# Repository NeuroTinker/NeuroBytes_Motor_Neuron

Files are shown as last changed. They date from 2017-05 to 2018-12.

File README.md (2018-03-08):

# NeuroBytes Motor Neuron
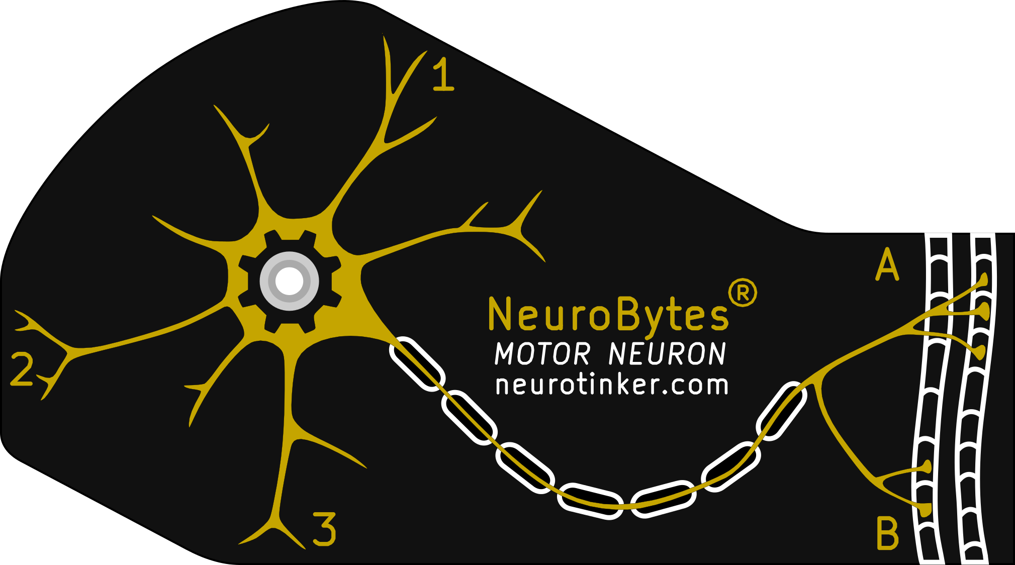
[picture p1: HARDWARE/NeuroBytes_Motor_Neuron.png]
NeuroBytes Motor Neuron PCB front

The NeuroBytes Motor Neuron is an open-source hardware neuron simulator designed and sold by [NeuroTinker, LLC](http://www.neurotinker.com/). 

All NeuroBytes products are based on the ST32L0x series of ARM Cortex-M0+ 32-bit microcontrollers. The boards were designed in KiCad and Inkscape and are released under the terms of the Creative Commons Attribution-ShareAlike 4.0 license, available here: http://creativecommons.org/licenses/by-sa/4.0/. The NeuroBytes Motor Neuron is Certified Open Source Hardware as defined by [OSHWA](https://www.oshwa.org), certification number US000109.


OSHWA Certification

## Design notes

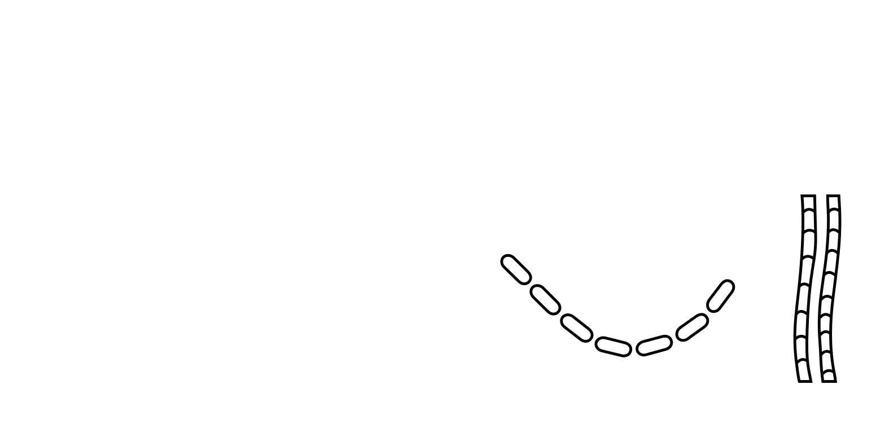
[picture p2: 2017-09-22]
HARDWARE/silk.png

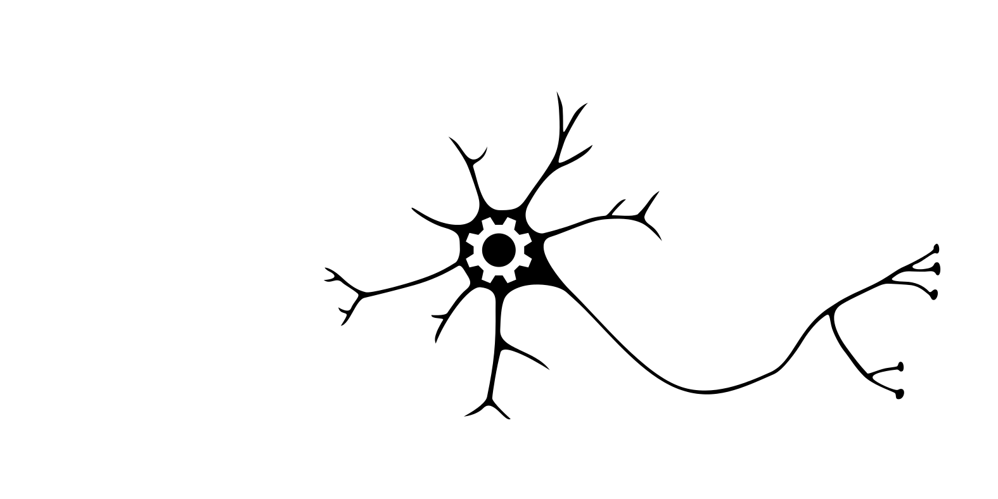
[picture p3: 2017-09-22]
HARDWARE/mask.png

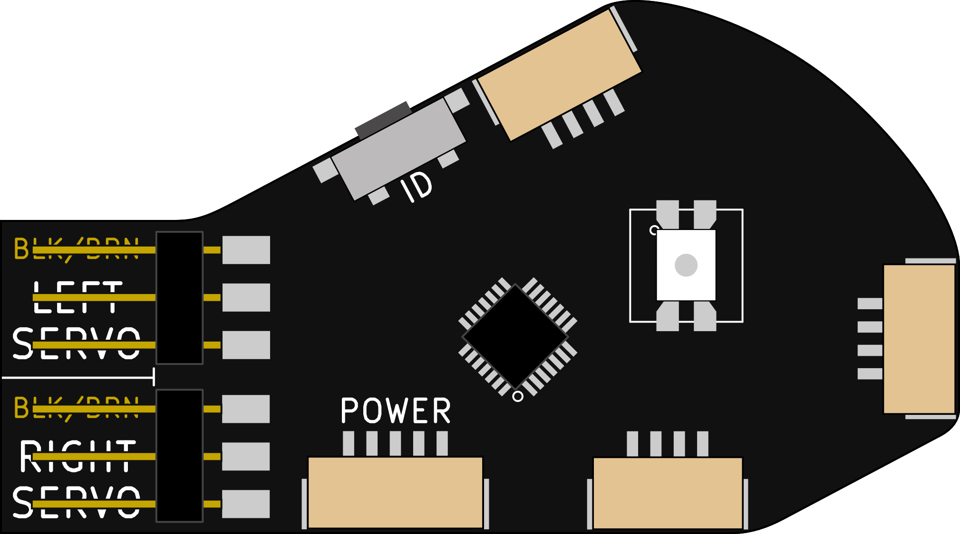
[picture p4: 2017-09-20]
HARDWARE/NeuroBytes_Motor_Neuron_back.png

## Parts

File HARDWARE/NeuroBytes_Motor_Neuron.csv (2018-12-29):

Ref | Qty | Value | Link | Mfr | Mfr Part # | Package | RoHS | Subs Allowed
C3 C5 | 2 | 0u1 | https://www.digikey.com/product-detail/en/taiyo-yuden/LMK105BJ104KV-F/587-1227-2-ND/930579 | Taiyo Yuden | LMK105BJ104KV-F | C0402 | Yes | Yes
C1 C4 | 2 | 1u | https://www.digikey.com/product-detail/en/taiyo-yuden/LMK107B7105KA-T/587-1242-2-ND/930594 | Taiyo Yuden | LMK107B7105KA-T | C0603 | Yes | Yes
C2 | 1 | 10u | https://www.digikey.com/product-detail/en/taiyo-yuden/EMK316B7106KL-TD/587-2395-2-ND/2178914 | Taiyo Yuden | EMK316B7106KL-TD | C1206 | Yes | Yes
C6 C7 | 2 | 22u | https://www.digikey.com/product-detail/en/taiyo-yuden/EMK316BB7226ML-T/587-4319-2-ND/5361244 | Taiyo Yuden | EMK316BB7226M | C1206 | Yes | Yes
D1 | 1 | LED_RABG | https://www.digikey.com/product-detail/en/sunled/XZMDKCBDDG45S-9/1497-1257-2-ND/4902045 | SunLED | XZMDKCBDDG45S-9 | SMT | Yes | No
P1 P2 P3 | 3 | JST_GH_4POS | https://www.digikey.com/product-detail/en/jst-sales-america-inc/SM04B-GHS-TB-LF-SN/455-1566-2-ND/807788 | JST | SM04B-GHS-TB(LF)(SN)- | SMT | Yes | No
P4 P5 | 2 | SERVO_CONN | https://www.digikey.com/product-detail/en/harwin-inc/M20-8890345/952-3232-ND/6565716 | Harwin | M20-8900305 | HDR_3POS_SMT | Yes | No
P6 | 1 | JST_GH_5-pos | https://www.digikey.com/product-detail/en/jst-sales-america-inc/SM05B-GHS-TB-LF-SN/455-1567-2-ND/807789 | JST | SM05B-GHS-TB(LF)(SN) | SMT | Yes | No
Q1 Q2 Q3 | 3 | MMBT3904 | https://www.digikey.com/product-detail/en/micro-commercial-co/MMBT3904-TP/MMBT3904TPMSTR-ND/717280 | Micro Commercial Co | MMBT3904-TP | SOT23-3L | Yes | Yes
R1 | 1 | 150 | https://www.digikey.com/product-detail/en/yageo/RC0402FR-07150RL/311-150LRCT-ND/729490 | Yageo | RC0402FR-07150RL | R0402 | Yes | Yes
R2 R3 | 2 | 100 | https://www.digikey.com/product-detail/en/yageo/RC0402FR-07100RL/311-100LRTR-ND/726527 | Yageo | RC0402FR-07100RL | R0402 | Yes | Yes
R4 | 1 | JMP | https://www.digikey.com/product-detail/en/yageo/RC0402JR-070RL/311-0.0JRTR-ND/726406 | Yageo | RC0402JR-070RL | R0402 | Yes | Yes
R5 R6 R7 | 3 | 1k | https://www.digikey.com/product-detail/en/yageo/RC0402FR-071KL/311-1.00KLRTR-ND/726513 | Yageo | RC0402FR-071KL | R0402 | Yes | Yes
SW1 | 1 | SW_PUSH | https://www.digikey.com/product-detail/en/e-switch/TL3330AF130QG/EG4388TR-ND/1426835 | E-Switch | TL3330AF130QG | SMT | Yes | No
U1 | 1 | STM32L011Gx | http://www.mouser.com/ProductDetail/STMicroelectronics/STM32L011G4U6/ | ST Microelectronics | STM32L011G4U6 | UFQFPN28 | Yes | No
U2 | 1 | LD3985G33R | https://www.digikey.com/product-detail/en/on-semiconductor/NCP114BSN330T1G/NCP114BSN330T1GOSTR-ND/6560606 | ON Semiconductor | NCP114BSN330T1G | SOT23-5L | Yes | Yes
U3 | 1 | RClamp0503F | https://www.digikey.com/product-detail/en/semtech-corporation/RCLAMP0503F.TCT/RCLAMP0503F.TCTTR-ND/5113629 | Semtech Corporation | RCLAMP0503F.TCT | 5-TSSOP | Yes | No
BOM made with KICAD_BOM_WIZARD (https://github.com/HashDefineElectronics/KiCad_BOM_Wizard.git)
Generated Wed 23 May 2018 03:11:21 PM CDT

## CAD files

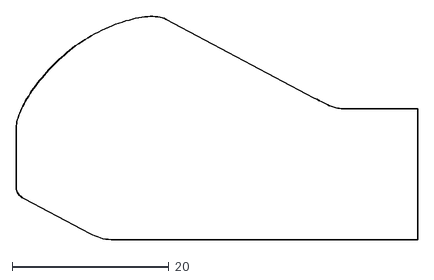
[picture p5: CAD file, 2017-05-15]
HARDWARE/NeuroBytes_Motor_Neuron.dxf
51.2 x 28.4

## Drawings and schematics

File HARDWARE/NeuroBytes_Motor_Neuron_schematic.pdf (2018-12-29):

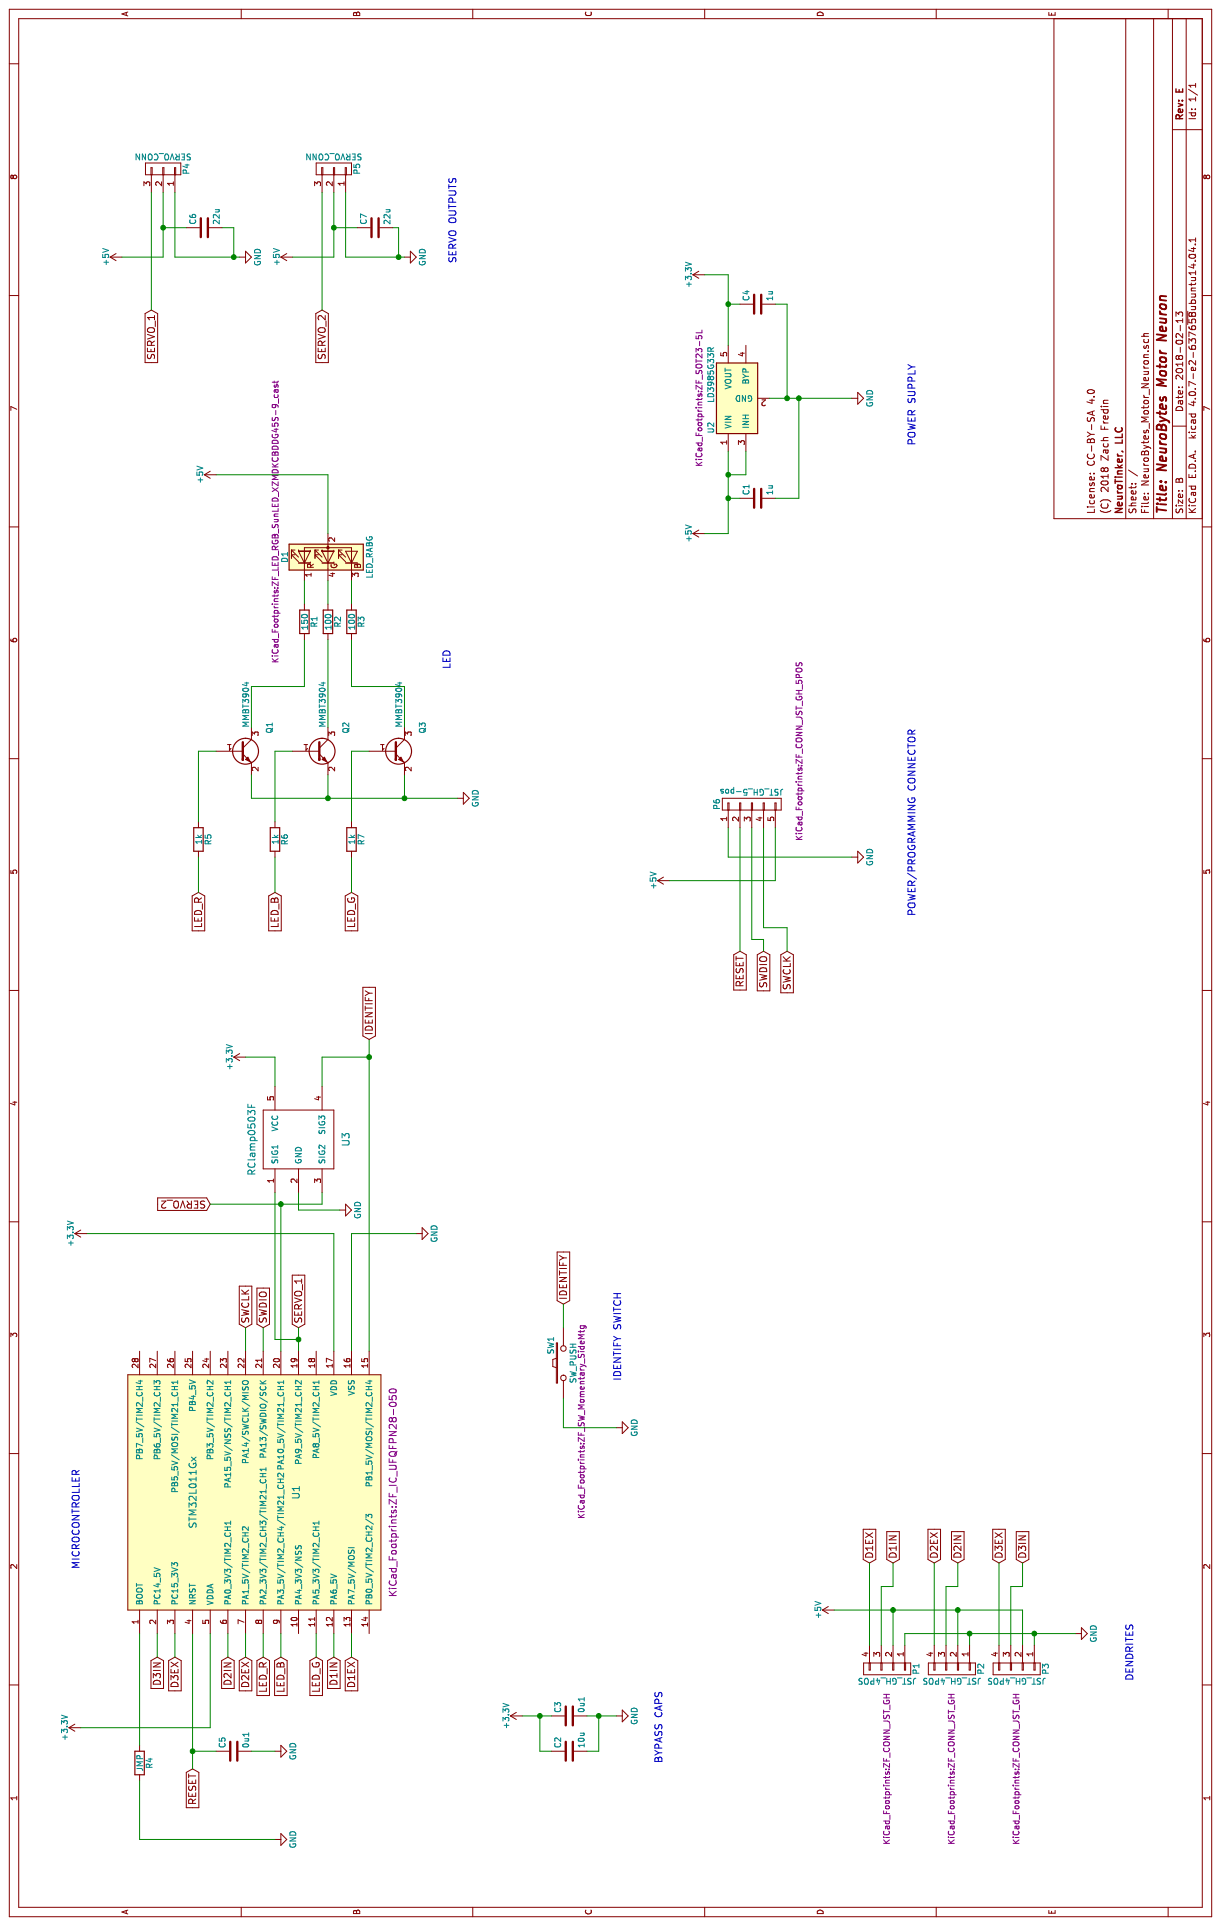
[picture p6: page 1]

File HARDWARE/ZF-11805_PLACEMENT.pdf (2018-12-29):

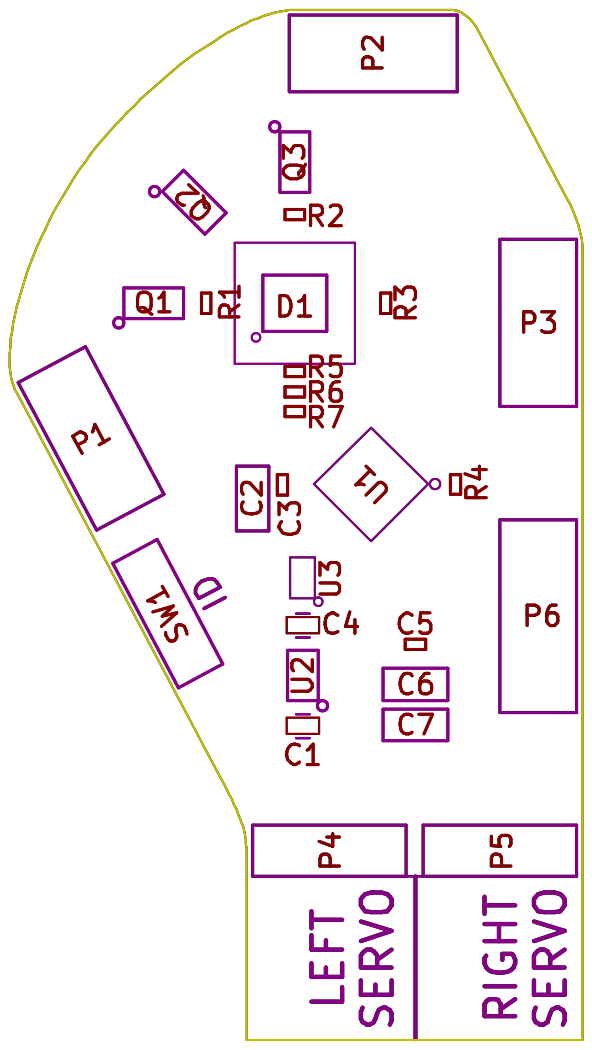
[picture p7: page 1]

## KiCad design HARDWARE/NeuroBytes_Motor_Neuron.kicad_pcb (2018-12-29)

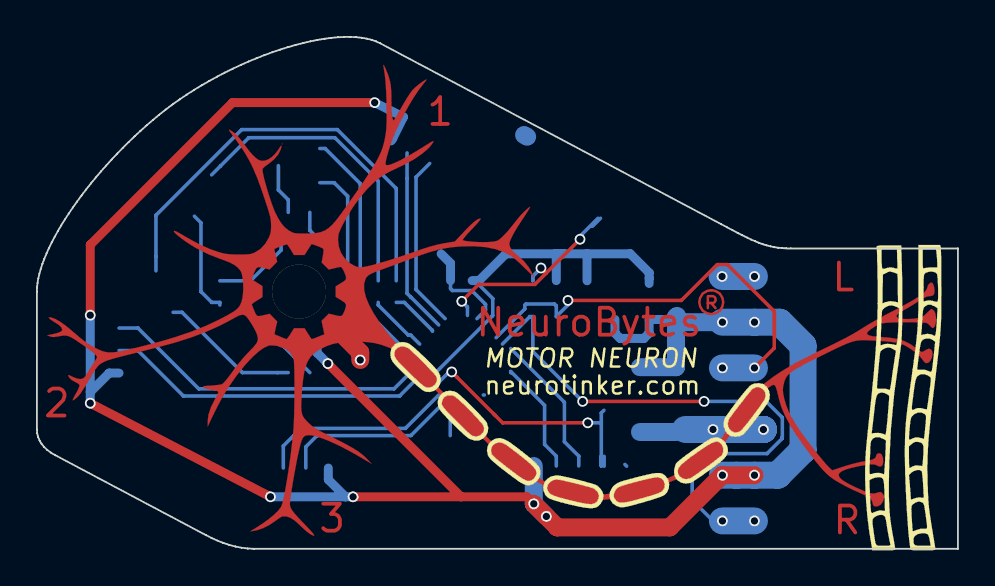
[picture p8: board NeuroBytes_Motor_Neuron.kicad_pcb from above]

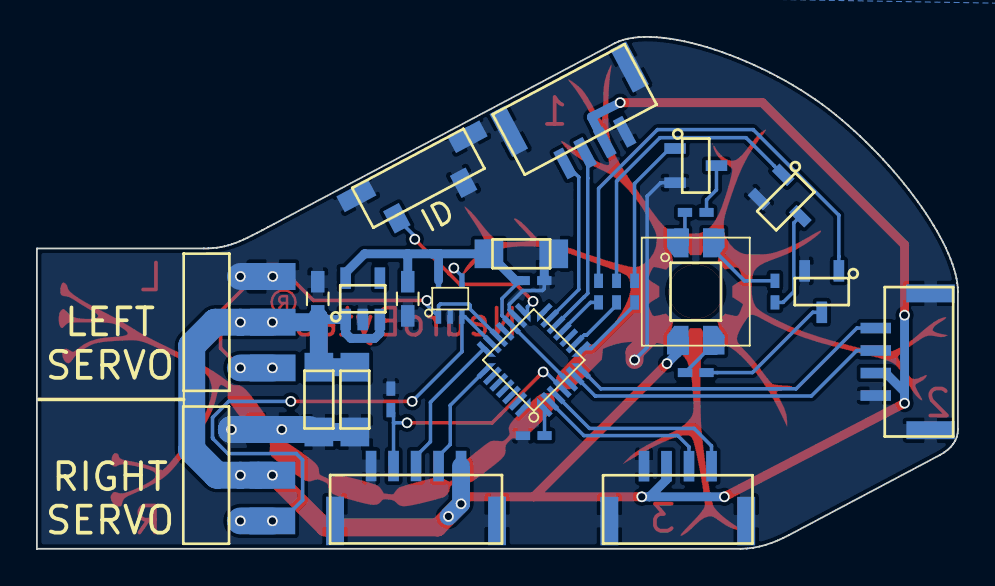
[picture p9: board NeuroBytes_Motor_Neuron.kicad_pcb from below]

Board: 2 copper layers, 51.2 x 28.4 mm, 28 parts (28 on the bottom side), 28 nets.

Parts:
C1, C4: 1u; C_0603_HandSoldering
C2: 10u; ZF_SMD_nonpol_1206
C3, C5: 0u1; ZF_SMD_NonPol_0402_cap
C6, C7: 22u; ZF_SMD_nonpol_1206
D1: LED_RABG; ZF_LED_RGB_SunLED_XZMDKCBDDG45S-9_cast
P1, P2, P3: JST_GH_4POS; ZF_CONN_JST_GH
P4, P5: SERVO_CONN; ZF_CONN_SERVO_HDR_SMT
P6: JST_GH_5-pos; ZF_CONN_JST_GH_5POS
Q1, Q2, Q3: MMBT3904; ZF_SOT23-3L
R1: 150; ZF_SMD_NonPol_0402
R2, R3: 100; ZF_SMD_NonPol_0402
R4: JMP; ZF_SMD_NonPol_0402
R5, R6, R7: 1k; ZF_SMD_NonPol_0402
SW1: SW_PUSH; ZF_SW_Momentary_SideMtg
U1: STM32L011Gx; ZF_IC_UFQFPN28-050
U2: LD3985G33R; ZF_SOT23-5L
U3: RClamp0503F; ZF_SMD_SOT-353

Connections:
+3V3: C2.1, C3.1, C4.1, U1.5, U1.17, U2.5, U3.5
+5V: C1.1, C6.1, C7.1, D1.2, P1.2, P2.2, P3.2, P4.2, P5.2, P6.5, U2.1, U2.3
D1EX: P1.4, U1.13
D1IN: P1.3, U1.12
D2EX: P2.4, U1.7
D2IN: P2.3, U1.6
D3EX: P3.4, U1.3
D3IN: P3.3, U1.2
GND: C1.2, C2.2, C3.2, C4.2, C5.2, C6.2, C7.2, P1.1, P2.1, P3.1, P4.1, P5.1, P6.1, Q1.2, Q2.2, Q3.2, R4.2, SW1.1, U1.16, U2.2, U3.2
IDENTIFY: SW1.2, U1.15, U3.4
LED_B: R6.2, U1.9
LED_G: R7.2, U1.11
LED_R: R5.2, U1.8
unnamed: D1.1, R1.1
unnamed: D1.3, R3.1
unnamed: D1.4, R2.1
unnamed: Q1.1, R5.1
unnamed: Q1.3, R1.2
unnamed: Q2.1, R6.1
unnamed: Q2.3, R2.2
unnamed: Q3.1, R7.1
unnamed: Q3.3, R3.2
unnamed: R4.1, U1.1
RESET: C5.1, P6.2, U1.4
SERVO_1: P4.3, U1.19, U3.1
SERVO_2: P5.3, U1.20, U3.3
SWCLK: P6.4, U1.22
SWDIO: P6.3, U1.21

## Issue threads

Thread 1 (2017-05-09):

Servos stuttering and getting a bit warm

zakqwy, 2017-05-09:
I 'scoped the servo PWM signal and the period is 8ms. Might need to lengthen to 20ms or more to work with the cheap 9g servos we use.

jrwhite, 2017-05-15:
I've lengthened the PWM period to 20ms in the most recent commit. With the new motor neurons and this new PWM period, I didn't notice any stuttering or warming.

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

Closed 2017-05-15.

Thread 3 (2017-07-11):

Motor Neurons don't work with CR and standard servos

zakqwy, 2017-07-11:
Current firmware doesn't extend standard servo horns very far. Bodged a tray together by changing setServo command denominators. Need to put together a decay curve that accommodates both types of actuators. Must work with both Vehicles and Patellar Reflex kits.

zakqwy, 2017-09-19:
updated to have mode switching and color indication (cyan for CR, yellow for std)

Closed 2017-09-19.

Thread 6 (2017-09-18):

save current servo mode (CR vs STD) to eeprom

zakqwy, 2017-09-18:

NeuroTinkerJoe, 2018-01-25:
on first power up, the motor neuron should default to non-CR controlling mode.

jrwhite, 2018-12-29:
implemented in latest merge

Closed 2018-12-29.

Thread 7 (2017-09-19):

intermittent freezing issue

zakqwy, 2017-09-19:
similar to photoreceptor -- see motor neuron malfunction log (engineering/products/malfunction_log/) for video. Hard to replicate and often clears on power cycle.

jrwhite, 2017-11-29:
Solved in current version of the development branch. This issue will stay open until the fix is merged to master

Closed 2018-01-30.

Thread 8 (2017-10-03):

change LED color and duration

zakqwy, 2017-10-03:
change from white AP flash to red/blue flash. increase flash duration to make it more obvious.

NeuroTinkerJoe, 2018-01-24:
revert to the standard Interneuron LED scheme, maintaining the unique motor neuron behavior of incoming excitation = CW servo rotation, incoming inhibition = CCW servo rotation.

zakqwy, 2018-01-25:
other notes: STD servo lighting scheme should rest at green; excitatory impulses should cause a white flash but no hyperpolarization; no changes to inhibitory impulses.

Closed 2018-12-29.

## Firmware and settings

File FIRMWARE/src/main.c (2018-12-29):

#include <libopencm3/stm32/rcc.h>
#include <libopencm3/stm32/gpio.h>
#include <libopencm3/stm32/timer.h>
#include <libopencm3/cm3/nvic.h>
#include <libopencm3/cm3/systick.h>
#include <libopencm3/stm32/exti.h>
#include <libopencm3/stm32/usart.h>

#include "HAL.h"
#include "comm.h"
#include "neuron.h"

#define BLINK_TIME			40
#define DATA_TIME			10
#define DEND_PING_TIME		200 // 1000 ms
#define	NID_PING_TIME		200 // 1000 ms
#define SEND_PING_TIME		80 // 80
#define BUTTON_PRESS_TIME	2
#define BUTTON_HOLD_TIME    100
#define LPUART_SETUP_TIME	100
#define CHANGE_NID_TIME 	200

typedef enum{
CR = 	1,
STD = 	0
} servo_type_t;

typedef enum{
    CURRENT     =   0b0001,
    DEND1       =   0b0010,
    DEND2       =   0b0011,
	DEND3       =   0b0100,
	PWM_SPAN	=	0b0101,
	PWM_ZERO	=	0b0111
} parameter_identifiers;

int main(void)
{
	uint32_t	blink_time = 0;
	uint32_t	wait_time = 0;
	uint16_t	data_time = 0;
	uint16_t	send_ping_time = 0;

	// Button debounce variables
	uint16_t	button_press_time = 0;
	uint8_t		button_armed = 0;
	uint16_t	button_status = 0;

	// NID channel (0 = unselected)
	uint32_t	nid_channel = 0b000;

	// Current servo type (temporary solution)
	servo_type_t servo_type = STD; 
	uint8_t saved_servo_type = eepromRead(SERVO_TYPE_ADDRESS);
	if (saved_servo_type == 0 || saved_servo_type == 1) servo_type = saved_servo_type;
	uint16_t servo_zero = 280; // CR = 280
	uint16_t servo_span = 50; // CR = 40

	// Comms helper variables
	uint16_t	lpuart_setup_time = 0;
	uint8_t		change_nid_time = 0;
	message_t	message; // for constructing messages to send to the communications routine

	neuron_t 	neuron;
	uint8_t		i;
	neuronInit(&neuron);
	// TODO: change the neuron init to be unique to each NB board
	neuron.dendrites[0].magnitude = 3000;
	neuron.dendrites[1].magnitude = 3000;
	neuron.dendrites[2].magnitude = 3000;
	neuron.dendrites[0].base_magnitude = 3000;
	neuron.dendrites[1].base_magnitude = 3000;
	neuron.dendrites[2].base_magnitude = 3000;
	commInit();

	// setup eeprom

	MMIO32(FLASH_MEM_INTERFACE_BASE + FLASH_PEKEYR) = FLASH_PEKEY1;
	MMIO32(FLASH_MEM_INTERFACE_BASE + FLASH_PEKEYR) = FLASH_PEKEY2;
	MMIO32(FLASH_MEM_INTERFACE_BASE + FLASH_PRGKEYR) = FLASH_PRGKEY1;
	MMIO32(FLASH_MEM_INTERFACE_BASE + FLASH_PRGKEYR) = FLASH_PRGKEY2;

	clock_setup();
	systick_setup(100); // comm clock in microseconds
	gpio_setup();
	tim_setup();
	gpio_setup();

	for(;;)
	{

		if (main_tick == 1){
			// 5 ms
			main_tick = 0;
			
			// check to see if nid ping hasn't been received in last NID_PING_TIME ticks
			if (nid_ping_time > 0){
				nid_ping_time -= 1;
				if (nid_ping_time == 0){
					// nid no longer connected
					nid_distance = 100; // reset nid_keep_alive
					nid_pin = 0; // clear the nid pin
					nid_pin_out = 0;
					nid_i = 13; // make this a macro like NO_NID_I
				}
			}

			if (change_nid_time++ > CHANGE_NID_TIME){
				change_nid_time = 0;
				closer_distance = nid_distance;
				closer_ping_count = 0;
			}

			if (lpuart_setup_time < LPUART_SETUP_TIME){
				lpuart_setup_time += 1;
			} else if (lpuart_setup_time == LPUART_SETUP_TIME){
				lpuart_setup_time += 1;
				lpuart_setup();
			}

			/*
				Check to see if any comms flags have been set.
				Process any data that came from the NID.
			*/

			if (comms_flag != 0){
				switch (comms_flag){
					case DEND1:
						neuron.dendrites[0].magnitude = comms_data;
						break;
					case DEND2:
						neuron.dendrites[1].magnitude = comms_data;
						break;
					case DEND3:
						neuron.dendrites[2].magnitude = comms_data;
						break;
					case PWM_SPAN:
						servo_span = comms_data;
						break;
					case PWM_ZERO:
						servo_zero = comms_data;
						break;
					default:
						break;
				}
				comms_flag = 0;
				comms_data = 0;
			}

			/*
				nid_channel is the current channel, if any, that the NeuroByte is using to communicate
				with the NID. nid_channel should be cleared when NID tries to set a new NeuroByte to 
				identify_channel.

				The communication routine sets identify_time to zero when a new identify command is received.
			*/

			// check for clear channel command
			if (identify_time < IDENTIFY_TIME){
				if (identify_time == 0){
					if ((identify_channel == 0) || (identify_channel == nid_channel)){
						nid_channel = 0;
					}
				}
				 identify_time += 1;
			}

			// check identify button
			button_status = gpio_get(PORT_IDENTIFY, PIN_IDENTIFY);

			// if identify button is pressed and identify_time < IDENTIFY_TIME (i.e. NID sent 'identify'' message), set new nid_channel
			if (button_status == 0){
				// debounce
				button_press_time += 1;
				if (button_press_time >= BUTTON_HOLD_TIME){
					button_armed = 2;
					blink_flag = 1;
				} else if (button_press_time >= BUTTON_PRESS_TIME){
					button_armed = 1;
				}
			} else{
				// button not pressed
				if (button_armed == 0){
					button_press_time = 0;
				} else if (button_armed == 1 && nid_i != NO_NID_I){
					nid_channel = identify_channel;
					identify_time = 1;
					button_armed = 0;
				} else if (button_armed == 2){
					if (servo_type == CR){
						servo_type = STD;
					} else if (servo_type == STD){
						servo_type = CR;
					}
					eepromProgram(SERVO_TYPE_ADDRESS, servo_type);
					button_armed = 0;
				}
				button_press_time = 0;
			}
		
			// send current membrane potential to NID if currently identified by NID
			if (nid_channel != 0){
				// send data every DATA_TIME ticks
				if (data_time++ > DATA_TIME){
					message.message = (((uint32_t) DATA_MESSAGE)) | ((uint16_t) neuron.potential);						
					data_time = 0;
					message.length = 32;
					message.message |= (nid_channel << 21);
					addWrite(NID_BUFF,(const message_t) message);
				}
			}
			if (comms_flag != 0){
				switch (comms_flag){
					case DEND1:
						neuron.dendrites[0].magnitude = comms_data;
						break;
					case DEND2:
						neuron.dendrites[1].magnitude = comms_data;
						break;
					case DEND3:
						neuron.dendrites[2].magnitude = comms_data;
						break;
					case PWM_ZERO:
						servo_zero = comms_data;
						break;
					case PWM_SPAN:
						servo_span = comms_data;
						break;
				}
				comms_flag = 0;
				comms_data = 0;
			}


			
			checkDendrites(&neuron);
			
			dendriteDecayStep(&neuron);
			membraneDecayStep(&neuron);

			neuron.potential = calcNeuronPotential(&neuron);
			neuron.potential += neuron.fire_potential;

			if (servo_type == CR) {
				setServo(0, (int32_t)((neuron.potential / 190) + 270) * 1);
				setServo(1, (int32_t)((neuron.potential / 190) - 270) * -1);
			} else {
				setServo(0, (int32_t)(280 + (neuron.potential / 35)));
				setServo(1, (int32_t)((neuron.potential / 35) - 280) * -1);
			}

			if (blink_flag != 0){
				setLED(200,0,300);
				blink_time = 1;
				blink_flag = 0;
			} else if (blink_time > 0){
				if (++blink_time == BLINK_TIME){
					setLED(200,0,0);
					blink_time = 0;
				}
			} else if (neuron.state == INTEGRATE){
				if (servo_type == STD) {
					if (neuron.potential > 10000){
							setLED(200,0,0);
					} else if (neuron.potential > 0){
						setLED(neuron.potential / 50, 200 - (neuron.potential / 50), 0);
					} else if (neuron.potential < -10000){
						setLED(0,0, 200);
					} else if (neuron.potential < 0){
						setLED(0, 200 + (neuron.potential / 50), -1 * neuron.potential / 50);
					} else{
						setLED(0,200,0);
					}
				} else if (servo_type == CR) {
					if (neuron.potential > 10000){
							setLED(500,0,0);
					} else if (neuron.potential > 0){
						uint8_t blue = 200 - 1 * neuron.potential / 50;
						if (blue < 0) blue = 0;
						setLED(neuron.potential / 20, 200 - neuron.potential / 50, blue);
					} else if (neuron.potential < -10000){
						setLED(0,0, 200);
					} else if (neuron.potential < 0){
						setLED(0, 200 + (neuron.potential / 50), 200 -1 * neuron.potential / 50);
					} else{
						setLED(0,200,200);
					}

				}
			}
		}
	}
}

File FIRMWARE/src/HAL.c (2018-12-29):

#include "HAL.h"
#include <libopencm3/stm32/usart.h>


volatile uint8_t tick = 0;
volatile uint8_t main_tick = 0;
volatile uint8_t read_tick = 0;

volatile uint16_t active_input_pins[NUM_INPUTS] = {[0 ... 5] = 0};

volatile uint8_t active_input_tick[NUM_INPUTS] = {[0 ... 5] = 0};

volatile uint16_t active_output_pins[NUM_INPUTS] = {[0 ... 5] = 0};

volatile uint32_t dendrite_pulses[NUM_DENDS] = {[0 ... NUM_DENDS-1] = 0};
volatile uint8_t dendrite_pulse_count = 0;

/* 

All available input pins are:

PIN_DEND1_EX,
PIN_DEND1_IN, 
PIN_DEND2_EX,
PIN_DEND2_IN,
PIN_DEND3_EX,
PIN_DEND3_IN
    
*/

uint32_t active_input_ports[NUM_INPUTS] = {
    PORT_DEND1_EX,
    PORT_DEND1_IN,
    PORT_DEND2_EX,
    PORT_DEND2_IN,
    PORT_DEND3_EX,
    PORT_DEND3_IN
};

uint32_t active_output_ports[NUM_INPUTS] = {
    PORT_DEND1_EX,
    PORT_DEND1_IN,
    PORT_DEND2_EX,
    PORT_DEND2_IN,
    PORT_DEND3_EX,
    PORT_DEND3_IN
};

const uint16_t complimentary_pins[NUM_INPUTS] = {
    PIN_DEND1_IN,
    PIN_DEND1_EX,
    PIN_DEND2_IN,
    PIN_DEND2_EX,
    PIN_DEND3_IN,
    PIN_DEND3_EX
};

const uint32_t complimentary_ports[NUM_INPUTS] = {
    PORT_DEND1_IN,
    PORT_DEND1_EX,
    PORT_DEND2_IN,
    PORT_DEND2_EX,
    PORT_DEND3_IN,
    PORT_DEND3_EX
};

volatile uint8_t dendrite_pulse_flag[NUM_INPUTS] = {[0 ... NUM_INPUTS-1] = 0};
volatile uint8_t dendrite_ping_flag[NUM_INPUTS] = {[0 ... NUM_INPUTS-1] = 0};

static uint32_t fingerprint[3] __attribute__((section (".fingerprint"))) __attribute__ ((__used__)) = {
	3, // device id
	1, // firmware version
	0  // unique id
};

bool checkVersion(uint8_t device_id, uint16_t version) {return (device_id == fingerprint[0]) && (version = fingerprint[1]) ? true : false;}

void clock_setup(void)
{
	// STM32F0 command:	rcc_clock_setup_in_hsi_out_48mhz();
	rcc_set_sysclk_source(RCC_HSI16);
	rcc_osc_on(RCC_HSI16);
}

void sys_tick_handler(void)
{
    if (++tick >= 50){
		main_tick = 1;
		tick = 0;
	}

	if (read_tick++ >= 2){
		writeBit();
		read_tick = 0;
	}

	readBit(read_tick);	
}

void systick_setup(int xms)
{
	
    systick_set_clocksource(STK_CSR_CLKSOURCE_EXT);
    STK_CVR = 0;
    //systick_set_reload(2 * xms);
	systick_set_reload(180);
    systick_counter_enable();
    systick_interrupt_enable();
	
}

void gpio_setup(void)
{
	/*	Enable GPIO clocks */
	rcc_periph_clock_enable(RCC_GPIOA);
	rcc_periph_clock_enable(RCC_GPIOB);
	rcc_periph_clock_enable(RCC_GPIOC);

	rcc_peripheral_enable_clock(&RCC_APB2ENR, RCC_APB2ENR_SYSCFGEN); // this line took a long time


	/*	Set up LED pins, NeuroBytes v1.01:
		Alternative Function Mode with no pullup/pulldown
		Output options: push-pull, high speed
		PIN_R_LED (PA2): AF2, TIM2_CH3
		PIN_G_LED (PA5): AF5, TIM2_CH1
		PIN_B_LED (PA3): AF2, TIM2_CH4
	*/

	gpio_mode_setup(PORT_R_LED, GPIO_MODE_AF, GPIO_PUPD_NONE, PIN_R_LED);
	gpio_mode_setup(PORT_G_LED, GPIO_MODE_AF, GPIO_PUPD_NONE, PIN_G_LED);
	gpio_mode_setup(PORT_B_LED, GPIO_MODE_AF, GPIO_PUPD_NONE, PIN_B_LED);
	gpio_set_output_options(PORT_R_LED, GPIO_OTYPE_PP, GPIO_OSPEED_HIGH, PIN_R_LED);
	gpio_set_output_options(PORT_G_LED, GPIO_OTYPE_PP, GPIO_OSPEED_HIGH, PIN_G_LED);
	gpio_set_output_options(PORT_B_LED, GPIO_OTYPE_PP, GPIO_OSPEED_HIGH, PIN_B_LED);
	gpio_set_af(PORT_R_LED, GPIO_AF2, PIN_R_LED);
	gpio_set_af(PORT_G_LED, GPIO_AF5, PIN_G_LED);
	gpio_set_af(PORT_B_LED, GPIO_AF2, PIN_B_LED);


	/*
		Setup servos:
		Servo 1 = PA9 (AF5 => TIM21_CH2)
		Servo 2 = PA10 (AF0 => TIM21_CH1)
	*/

	gpio_mode_setup(PORT_SERVO1, GPIO_MODE_AF, GPIO_PUPD_PULLDOWN, PIN_SERVO1);
	gpio_mode_setup(PORT_SERVO2, GPIO_MODE_AF, GPIO_PUPD_PULLDOWN, PIN_SERVO2);
	gpio_set_output_options(PORT_SERVO1, GPIO_OTYPE_PP, GPIO_OSPEED_HIGH, PIN_SERVO1);
	gpio_set_output_options(PORT_SERVO2, GPIO_OTYPE_PP, GPIO_OSPEED_HIGH, PIN_SERVO2);
	gpio_set_af(PORT_SERVO1, GPIO_AF5, PIN_SERVO1);
	gpio_set_af(PORT_SERVO2, GPIO_AF0, PIN_SERVO2);

	//gpio_mode_setup(PORT_SERVO1, GPIO_MODE_OUTPUT, GPIO_PUPD_PULLDOWN, PIN_SERVO1); // debug
	//gpio_mode_setup(PORT_SERVO2, GPIO_MODE_OUTPUT, GPIO_PUPD_PULLDOWN, PIN_SERVO2); // debug

	gpio_mode_setup(PORT_IDENTIFY, GPIO_MODE_INPUT, GPIO_PUPD_PULLUP, PIN_IDENTIFY);

	/*
		All dendrites pins are initially set to be inputs.
		Setup dendrite pins:
		Dendrite 1 Excit/Inhib-- PB0/PB1 
	*/

	setAsInput(PORT_DEND1_EX, PIN_DEND1_EX);
	setAsInput(PORT_DEND1_IN, PIN_DEND1_IN);
	setAsInput(PORT_DEND2_EX, PIN_DEND2_EX);
	setAsInput(PORT_DEND2_IN, PIN_DEND2_IN);	
	setAsInput(PORT_DEND3_EX, PIN_DEND3_EX);
	setAsInput(PORT_DEND3_IN, PIN_DEND3_IN);


	nvic_enable_irq(NVIC_EXTI0_1_IRQ);
	nvic_enable_irq(NVIC_EXTI2_3_IRQ);
	nvic_enable_irq(NVIC_EXTI4_15_IRQ);

	nvic_set_priority(NVIC_EXTI0_1_IRQ, 0);
	nvic_set_priority(NVIC_EXTI2_3_IRQ, 0);
	nvic_set_priority(NVIC_EXTI4_15_IRQ, 0);

}

void lpuart_setup(void)
{
	// seutp lpuart interface (for communicating with NID)
	// NOTE: this ocnverts the swd interface to lpuart so debugging with swd will be disables
	rcc_periph_clock_enable(RCC_LPUART1);

	gpio_mode_setup(PORT_LPUART1_RX, GPIO_MODE_AF, GPIO_PUPD_NONE, PIN_LPUART1_RX);
	gpio_mode_setup(PORT_LPUART1_TX, GPIO_MODE_AF, GPIO_PUPD_NONE, PIN_LPUART1_TX);

	gpio_set_af(PORT_LPUART1_RX, GPIO_AF6, PIN_LPUART1_RX);
	gpio_set_af(PORT_LPUART1_TX, GPIO_AF6, PIN_LPUART1_TX);

	USART_BRR(LPUART1) = 0x1A0AA; // 38400 baud
	usart_set_databits(LPUART1, 8);  // USART_CR1_M
	usart_set_stopbits(LPUART1, USART_STOPBITS_1); //USART_CR2_STOP
	usart_set_mode(LPUART1, USART_MODE_TX_RX); //USART_CR1_RE USART_CR1_TE
	usart_set_parity(LPUART1, USART_PARITY_NONE);// USART_CR1_PS USART_CR1_PCE
	usart_set_flow_control(LPUART1, USART_FLOWCONTROL_NONE); // USART_CR3_RTSE USART_CR3_CTSE

	usart_enable(LPUART1); // USART_CR1_UE

	// enable interrupts
	nvic_enable_irq(NVIC_LPUART1_IRQ);
	usart_enable_rx_interrupt(LPUART1); // USART_CR1_RXNEIE
    USART_CR1(LPUART1) |= USART_CR1_RE;
    USART_CR1(LPUART1) |= USART_CR1_TE;
}

void lpuart1_isr(void)
{
    if ((USART_ISR(LPUART1) & USART_ISR_RXNE) != 0){
        readNID();
        USART_RQR(LPUART1) = 0b1000;
        USART_CR1(LPUART1) |= USART_CR1_RE;
    } else if ((USART_ISR(LPUART1) & USART_ISR_TXE) != 0){
        /* USART_CR1(LPUART1) |= USART_CR1_TE; */
        writeNID();
        USART_RQR(LPUART1) |= USART_RQR_TXFRQ;
    }
    USART_ICR(LPUART1) = USART_ISR(LPUART1);
}

void setAsInput(uint32_t port, uint32_t pin)
{
	// setup gpio as an input pin
	gpio_mode_setup(port, GPIO_MODE_INPUT, GPIO_PUPD_PULLDOWN, pin);

	// setup interrupt for the pin going high
	exti_select_source(pin, port);
	exti_set_trigger(pin, EXTI_TRIGGER_RISING);
	exti_enable_request(pin);
	exti_reset_request(pin);
}

void setAsOutput(uint32_t port, uint32_t pin)
{
	// disable input interrupts
	exti_disable_request(pin);

	// setup gpio as an output pin. pulldown
	gpio_mode_setup(port, GPIO_MODE_OUTPUT, GPIO_PUPD_PULLDOWN, pin);
}
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

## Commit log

2017-04-24 Added first gen hardware design files. No firmware yet beyond basic LED testing.
    [Motor_Neuron.dxf, NeuroBytes_Motor_Neuron.dxf, NeuroBytes_Motor_Neuron.kicad_pcb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]
2017-05-15 servos work now
2017-05-15 changed PWM period to 20.3 Hz
2017-05-15 added schematic library submodule
2017-05-15 Hardware v3. Changed headers to 3-position JST GH headers. Modified graphics and PCB outline -- now convex-ish, and includes parallel faces for V-scoring and routing.
    [Motor_Neuron.dxf, NeuroBytes_Motor_Neuron.dxf, NeuroBytes_Motor_Neuron.kicad_pcb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]
2017-05-26 Updated schematic global label 'SWITCH' to read 'IDENTIFY' (as with other NeuroBytes boards). Updated PCB LED footprint so silkscreen is correct (no routing changes).
    [NeuroBytes_Motor_Neuron.kicad_pcb, NeuroBytes_Motor_Neuron.sch]
2017-06-03 updated switch and header footprints. changed to nonpolarized tank caps. split resistor network and dual transistors into discrete components. other minor tweaks.
    [NeuroBytes_Motor_Neuron.kicad_pcb, NeuroBytes_Motor_Neuron.sch]
2017-08-11 changed to 5-pin JST GH connector for power and programming. Added POWER label and increased ID label size to standard (1.2 / 0.17). Minor routing and labeling updates.
    [NeuroBytes_Motor_Neuron.kicad_pcb, NeuroBytes_Motor_Neuron.sch]
2017-08-11 device id
2017-08-11 changed fingerprint address
2017-08-28 added kicad fonts to *.svg. added *.png render of pcb front.
2017-09-06 update readme.md with board front render
2017-09-07 updated schematic library
2017-09-14 fixed inhibitory/excitatory issue
    [_saved_NeuroBytes_Motor_Neuron.sch]
2017-09-18 added mode switch to motor neuron for CR/std servos. changed lighting scheme (CR = cyan, std = yellow).
2017-09-19 updated servo labels
    [NeuroBytes_Motor_Neuron.kicad_pcb]
2017-09-20 updated graphics to reflect new servo markings
2017-09-22 updated board graphics to reflect updated gear. other minor updates.
    [NeuroBytes_Motor_Neuron.csv, NeuroBytes_Motor_Neuron.kicad_pcb, NeuroBytes_Motor_Neuron.sch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]
2017-09-22 removed old save file
    [_saved_NeuroBytes_Motor_Neuron.sch]
2017-09-22 reloaded netlist. minor PCB changes.
    [NeuroBytes_Motor_Neuron.kicad_pcb]
2017-10-03 minor page layout updates
    [NeuroBytes_Motor_Neuron.kicad_pcb, NeuroBytes_Motor_Neuron.sch]
2017-11-21 fixed pin errors
2017-11-27 adjusted PWM params and dendrite weightings
2017-11-28 support for PWM cmd
2017-11-29 fixed servo_zero
2017-11-29 updated license to CC-BY-SA 4.0. updated readme. added drawing no. to PCB.
    [NeuroBytes_Motor_Neuron.kicad_pcb]
2018-02-01 fixed PWM params
2018-02-13 added ESD protection. minor routing changes. updated title block.
    [NeuroBytes_Motor_Neuron.kicad_pcb, NeuroBytes_Motor_Neuron.sch]
2018-03-08 minor PCB render updates
2018-03-15 increased blue servo range
2018-05-23 added fab files and BOM
    [NeuroBytes_Motor_Neuron-B.Cu.gbr, NeuroBytes_Motor_Neuron-B.Mask.gbr, NeuroBytes_Motor_Neuron-B.Paste.gbr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]
2018-05-31 added schematic *.pdf
2018-08-08 updated footprints to include B.Fab outlines. minor routing changes. re-generated Gerbers. added placement pdf.
    [NeuroBytes_Motor_Neuron-B.Cu.gbr, NeuroBytes_Motor_Neuron-B.Fab.gbr, NeuroBytes_Motor_Neuron-B.Mask.gbr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]
2018-08-08 regen drill file
    [NeuroBytes_Motor_Neuron.drl]
2018-12-29 write servo_type to eeprom

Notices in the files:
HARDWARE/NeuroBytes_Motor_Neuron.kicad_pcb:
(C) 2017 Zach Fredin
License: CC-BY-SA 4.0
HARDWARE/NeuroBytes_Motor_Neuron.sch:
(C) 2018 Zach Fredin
